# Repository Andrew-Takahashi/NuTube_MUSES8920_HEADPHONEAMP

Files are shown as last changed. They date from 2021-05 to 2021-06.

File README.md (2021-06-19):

# NuTube_MUSES8920_HEADPHONEAMP

## Version 2 updated

Version 1の配線ミスを修正し，オペアンプを両電源化．

ついでにアノード負荷を変更して2.5+-1Vで使えるように調整．

これによりNuTube単体での増幅率は約3.38倍(10.59 dB)に．

さらにオペアンプのバイアス電流をキャンセルするための抵抗用パッドを追加(R7,R11)．

電源回りのEMIフィルタをコモンモードチョークコイル + 貫通コンデンサで強化．

頑張って小型化して100 * 100 mmにした．

まだ動作確認してないので自己責任でどうぞ．

## Version 1

名前の通りNuTubeとMUSES8920を使ったヘッドホンアンプ．
現状ではNuTubeの配線を間違えているので修正予定．
ついでに両電源化してオペアンプ出力カップリングコンデンサをなくす予定．

参考(前段はパクリ)
www.maroon.dti.ne.jp/jyaku9/electronic/electronic5/electronic5-2.html

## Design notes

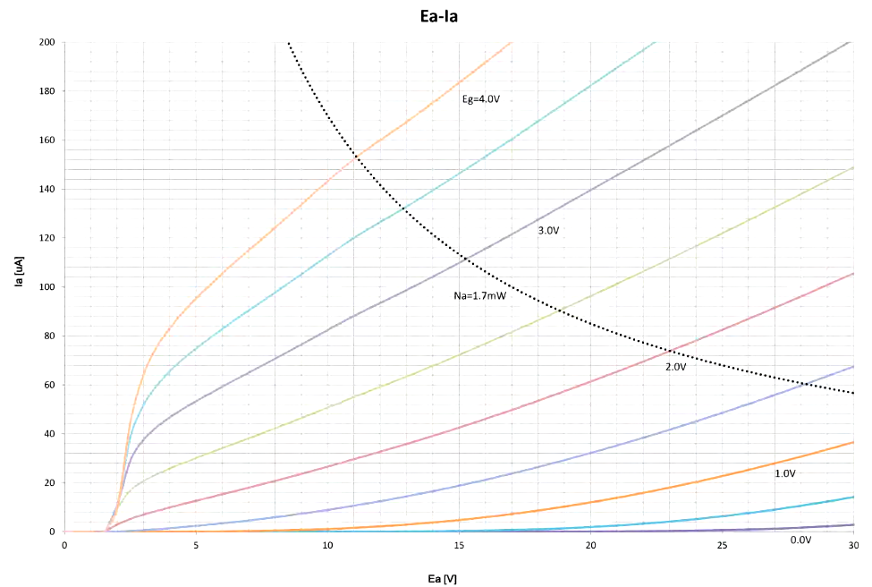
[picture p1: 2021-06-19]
Ea-Ia_.png

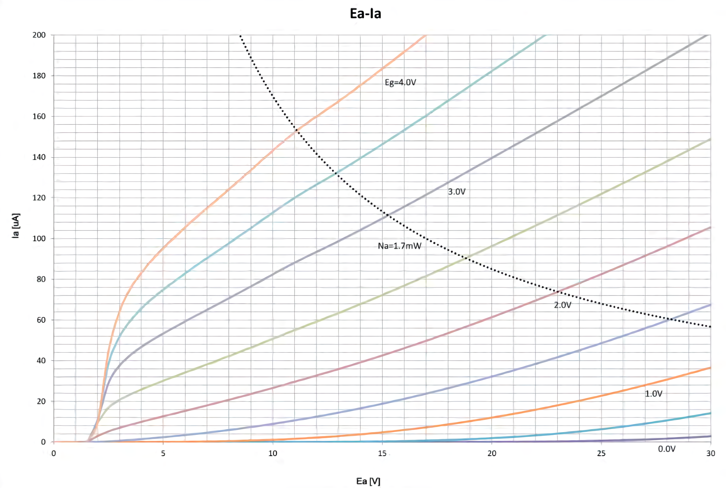
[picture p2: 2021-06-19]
Ea-Ia__.png

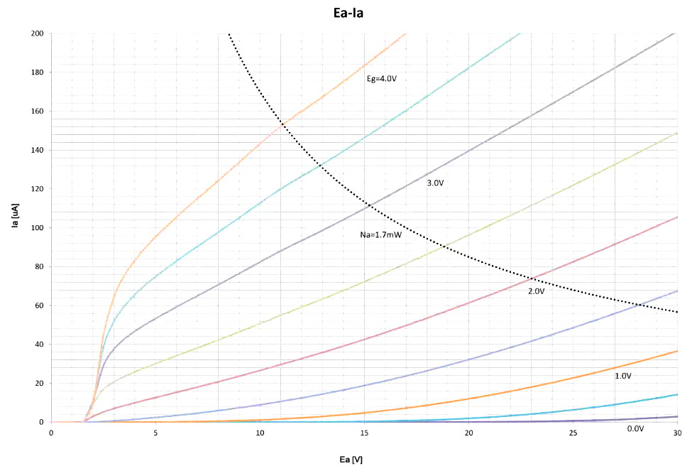
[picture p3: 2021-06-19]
Ea-Ia_.jpg

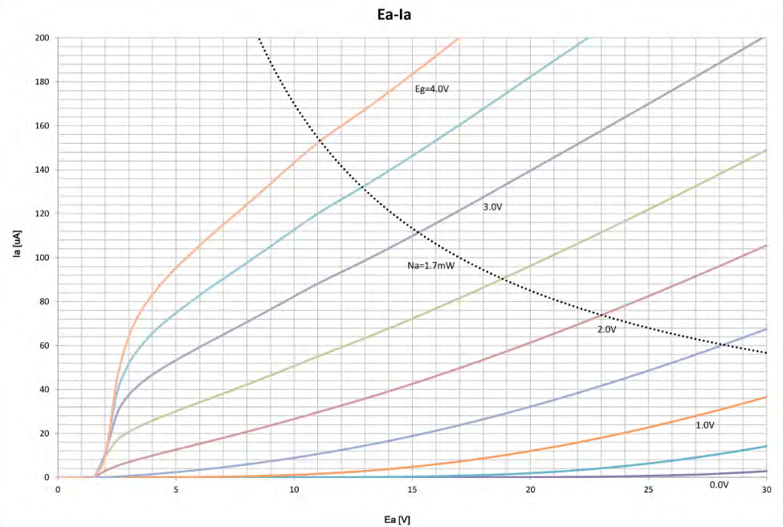
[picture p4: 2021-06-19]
Ea-Ia.bmp

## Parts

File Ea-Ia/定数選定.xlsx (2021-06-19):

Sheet: Anode Load
Load line
Ra | Intercept | Slope
100 | 150 | -10
110 | 136.3636364 | -9.090909091
120 | 125 | -8.333333333
130 | 115.3846154 | -7.692307692
150 | 100 | -6.666666667
160 | 93.75 | -6.25
180 | 83.33333333 | -5.555555556
200 | 75 | -5
220 | 68.18181818 | -4.545454545
240 | 62.5 | -4.166666667
270 | 55.55555556 | -3.703703704
300 | 50 | -3.333333333
330 | 45.45454545 | -3.03030303
Eg-Ea
 | 100k |  | 120k |  | 150k
Eg | Ea | Ia | Ea | Ia | Ea | Ia
4 | 5.28 | 98.11 | 4.39 | 88.3 | 3.55 | 76.55
3.5 | 6.35 | 85.68 | 5.43 | 78.31 | 4.49 | 70.24
3 | 8.03 | 70.81 | 7.29 | 66.69 | 6.01 | 59.39
2.5 | 9.9 | 50.22 | 9.34 | 47.81 | 8.41 | 43.85
2 | 11.88 | 32.21 | 11.32 | 30.48 | 10.75 | 28.81 |  | 14.63 | 42.66
1.5 | 13.49 | 15.41 | 13.3 | 14.98 | 12.94 | 14.2 |  | 14.443 | 40.905
1 | 14.63 | 42.66 | 14.54 | 41.78 | 14.443 | 40.905
Gain | -3.116666667 |  | -3.383333333 |  | -3.631 |  |  | 14.5365 | 41.7825
 | 9.873807123 |  | 10.58689575 |  | 11.20052498
 | slope | intercept | slope | intercept | slope | intercept
 | -3.85 | 19.56166667 | -4.03 | 19.39166667 | -4.74 | 20.24
Eg | Ea | RMS | Ea | RMS | Ea | RMS
4 | 4.161666667 | 1.250669444 | 3.271666667 | 1.250669444 | 1.28 | 5.1529
3.5 | 6.086666667 | 0.06934444444 | 5.286666667 | 0.02054444444 | 3.65 | 0.7056
3 | 8.011666667 | 0.0003361111111 | 7.301666667 | 0.0001361111111 | 6.02 | 0.0001
2.5 | 9.936666667 | 0.001344444444 | 9.316666667 | 0.0005444444444 | 8.39 | 0.0004
2 | 11.86166667 | 0.0003361111111 | 11.33166667 | 0.0001361111111 | 10.76 | 0.0001
1.5 | 13.78666667 | 0.08801111111 | 13.34666667 | 0.002177777778 | 13.13 | 0.0361
1 | 15.71166667 | 1.170002778 | 15.36166667 | 0.6751361111 | 15.5 | 1.117249
linearity error(2.5+-1V) |  | 0.03187444444 |  | 0.004707777778 |  | 0.14846
 |  | Dumping
 | Impedance | 16 | 18 | 20 | 22 | 24 | 27 | 30 | 33 | 36 | 39 | 43 | 47 | 51 | 56 | 62 | 68 | 75
MPH-2 | 32 | -0.3333333333 | -0.28 | -0.2307692308 | -0.1851851852 | -0.1428571429 | -0.08474576271 | -0.03225806452 | 0.01538461538 | 0.05882352941 | 0.0985915493 | 0.1466666667 | 0.1898734177 | 0.2289156627 | 0.2727272727 | 0.3191489362 | 0.36 | 0.4018691589
SE-CH9T | 26 | -0.2380952381 | -0.1818181818 | -0.1304347826 | -0.08333333333 | -0.04 | 0.01886792453 | 0.07142857143 | 0.1186440678 | 0.1612903226 | 0.2 | 0.2463768116 | 0.2876712329 | 0.3246753247 | 0.3658536585 | 0.4090909091 | 0.4468085106 | 0.4851485149
E500 | 16 | 0 | 0.05882352941 | 0.1111111111 | 0.1578947368 | 0.2 | 0.2558139535 | 0.3043478261 | 0.3469387755 | 0.3846153846 | 0.4181818182 | 0.4576271186 | 0.4920634921 | 0.5223880597 | 0.5555555556 | 0.5897435897 | 0.619047619 | 0.6483516484
 |  | 0.02947845805 | 0.03039158111 | 0.03088226474 | 0.03104476908 | 0.03095510204 | 0.03047668952 | 0.02971763721 | 0.0287848582 | 0.02775230999 | 0.02667081994 | 0.02521086799 | 0.02377657488 | 0.02239771438 | 0.02077519517 | 0.01899106934 | 0.01738461615 | 0.01572072192

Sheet: Parts List
 |  |  |  | D | P | L
C1 | EMIフィルタ |  |  |  |  |  | https://akizukidenshi.com/catalog/g/gP-05494/ | 200
C2 | EMIフィルタ |  |  |  |  |  | https://akizukidenshi.com/catalog/g/gP-05494/
C3 | 3.3V IGO IN | 0.1 | ECHU | 3225 |  |  | https://akizukidenshi.com/catalog/g/gP-14342/ | 40
C4 | 3.3V IGO IN | 0.1 | ECHU | 3225 |  |  | https://akizukidenshi.com/catalog/g/gP-14342/ | 40
C5 | 3.3V IGO OUT | 100 | OS | 6.3 | 2.5 | 6 | https://akizukidenshi.com/catalog/g/gP-08290/ | 40
C6 | 3.3V IGO OUT | 100 | OS | 6.3 | 2.5 | 6 | https://akizukidenshi.com/catalog/g/gP-08290/ | 40
C7 | COUPLE IN | 100 | KZ | 10 | 5 | 16 | https://akizukidenshi.com/catalog/g/gP-04608/ | 30
C8 | BIAS | 22 | ES | 6.3 | 2.5 | 11 | https://akizukidenshi.com/catalog/g/gP-04625/ | 20
C9 | COUPLE IN | 100 | KZ | 10 | 5 | 16 | https://akizukidenshi.com/catalog/g/gP-04608/ | 30
C10 | BIAS | 22 | ES | 6.3 | 2.5 | 11 | https://akizukidenshi.com/catalog/g/gP-04625/ | 20
C11 | Anode CP | 100 | OS | 6.3 | 2.5 | 6 | https://akizukidenshi.com/catalog/g/gP-08290/ | 40
C12 | Anode C | 0.1 | ECHU | 3225 |  |  | https://akizukidenshi.com/catalog/g/gP-14342/ | 40
C13 | Filament CP | 22 | ES | 6.3 | 2.5 | 11 | https://akizukidenshi.com/catalog/g/gP-04625/ | 20
C14 | Filament CP | 22 | ES | 6.3 | 2.5 | 11 | https://akizukidenshi.com/catalog/g/gP-04625/ | 20
C15 | Anode C | 0.1 | ECHU | 3225 |  |  | https://akizukidenshi.com/catalog/g/gP-14342/ | 40
C16 | Anode CP | 100 | OS | 6.3 | 2.5 | 6 | https://akizukidenshi.com/catalog/g/gP-08290/ | 40
C17 | COUPLE AMP | 100 | KZ | 10 | 5 | 16 | https://akizukidenshi.com/catalog/g/gP-04608/ | 30
C18 | COUPLE AMP | 100 | KZ | 10 | 5 | 16 | https://akizukidenshi.com/catalog/g/gP-04608/ | 30
C19 | DCPL AMP | 100 | OS | 6.3 | 2.5 | 6 | https://akizukidenshi.com/catalog/g/gP-08290/ | 40
C20 | DCPL AMP | 100 | OS | 6.3 | 2.5 | 6 | https://akizukidenshi.com/catalog/g/gP-08290/ | 40
C21 | DCPL AMP | 0.1 | ECHU | 3225 |  |  | https://akizukidenshi.com/catalog/g/gP-14342/ | 40
C22 | DCPL AMP | 0.1 | ECHU | 3225 |  |  | https://akizukidenshi.com/catalog/g/gP-14342/ | 40
R1 | 33k
R2 | 150
R3 | 33k
R4 | 150
R5 | 120k
R6 | 120k
R7 | 1M
R8 | 1k
R9 | 1k
R10 | 75
R11 | 1M
R12 | 1k
R13 | 1k
R14 | 75

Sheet: Buy List
 |  | 単価 | 個数 | 小計
ＥＭＩフィルタ（ムラタエミフィル・フィールドスルーコンデンサー） １μＦ（１０個入） | https://akizukidenshi.com/catalog/g/gP-05494/ | 200 | 1 | 200
メタライズド積層フィルムコンデンサー ０．１μＦ１６Ｖ パナソニックＥＣＨＵ | https://akizukidenshi.com/catalog/g/gP-14342/ | 40 | 20 | 800
導電性高分子アルミ固体電解コンデンサー ＯＳ－ＣＯＮ １００μＦ１６Ｖ１０５℃ | https://akizukidenshi.com/catalog/g/gP-08290/ | 40 | 20 | 800
オーディオ用電解コンデンサー１００μＦ２５Ｖ８５℃ ニチコンＭＵＳＥ・ＫＺ | https://akizukidenshi.com/catalog/g/gP-04608/ | 30 | 10 | 300
オーディオ用無極性電解コンデンサー２２μＦ２５Ｖ８５℃ ニチコンＭＵＳＥ・ＥＳ | https://akizukidenshi.com/catalog/g/gP-04625/ | 20 | 10 | 200
マイクロＵＳＢコネクタ 電源供給用 | https://akizukidenshi.com/catalog/g/gC-10398/ | 30 | 10 | 300
３．５ｍｍ４極ミニジャック 基板取付用 ＭＪ－４ＰＰ－９ | https://akizukidenshi.com/catalog/g/gC-06070/ | 50 | 4 | 200
多回転半固定ボリューム たて型 ３２９６Ｗ １０ｋΩ ［１０３］ | https://akizukidenshi.com/catalog/g/gP-00975/ | 120 | 8 | 960
コモンモードチョーク（ノイズフィルタ） ＤＬＷ５ＢＴＭ１４２ＴＱ２ | https://akizukidenshi.com/catalog/g/gP-15303/ | 100 | 10 | 1000
1608(0603) チップ抵抗 75Ω | https://www.marutsu.co.jp/pc/i/856891/ | 5 | 10 | 50
1608(0603) チップ抵抗 150Ω | https://www.marutsu.co.jp/pc/i/856769/ | 5 | 10 | 50
1608(0603) チップ抵抗 1kΩ | https://www.marutsu.co.jp/pc/i/856745/ | 5 | 20 | 100
1608(0603) チップ抵抗 33kΩ | https://www.marutsu.co.jp/pc/i/856829/ | 5 | 10 | 50
1608(0603) チップ抵抗 120kΩ | https://www.marutsu.co.jp/pc/i/856760/ | 5 | 10 | 50
1608(0603) チップ抵抗 470kΩ | https://www.marutsu.co.jp/pc/i/856859/ | 5 | 20 | 100
1608(0603) チップ抵抗 1MΩ | https://www.marutsu.co.jp/pc/i/856748/ | 5 | 20 | 100

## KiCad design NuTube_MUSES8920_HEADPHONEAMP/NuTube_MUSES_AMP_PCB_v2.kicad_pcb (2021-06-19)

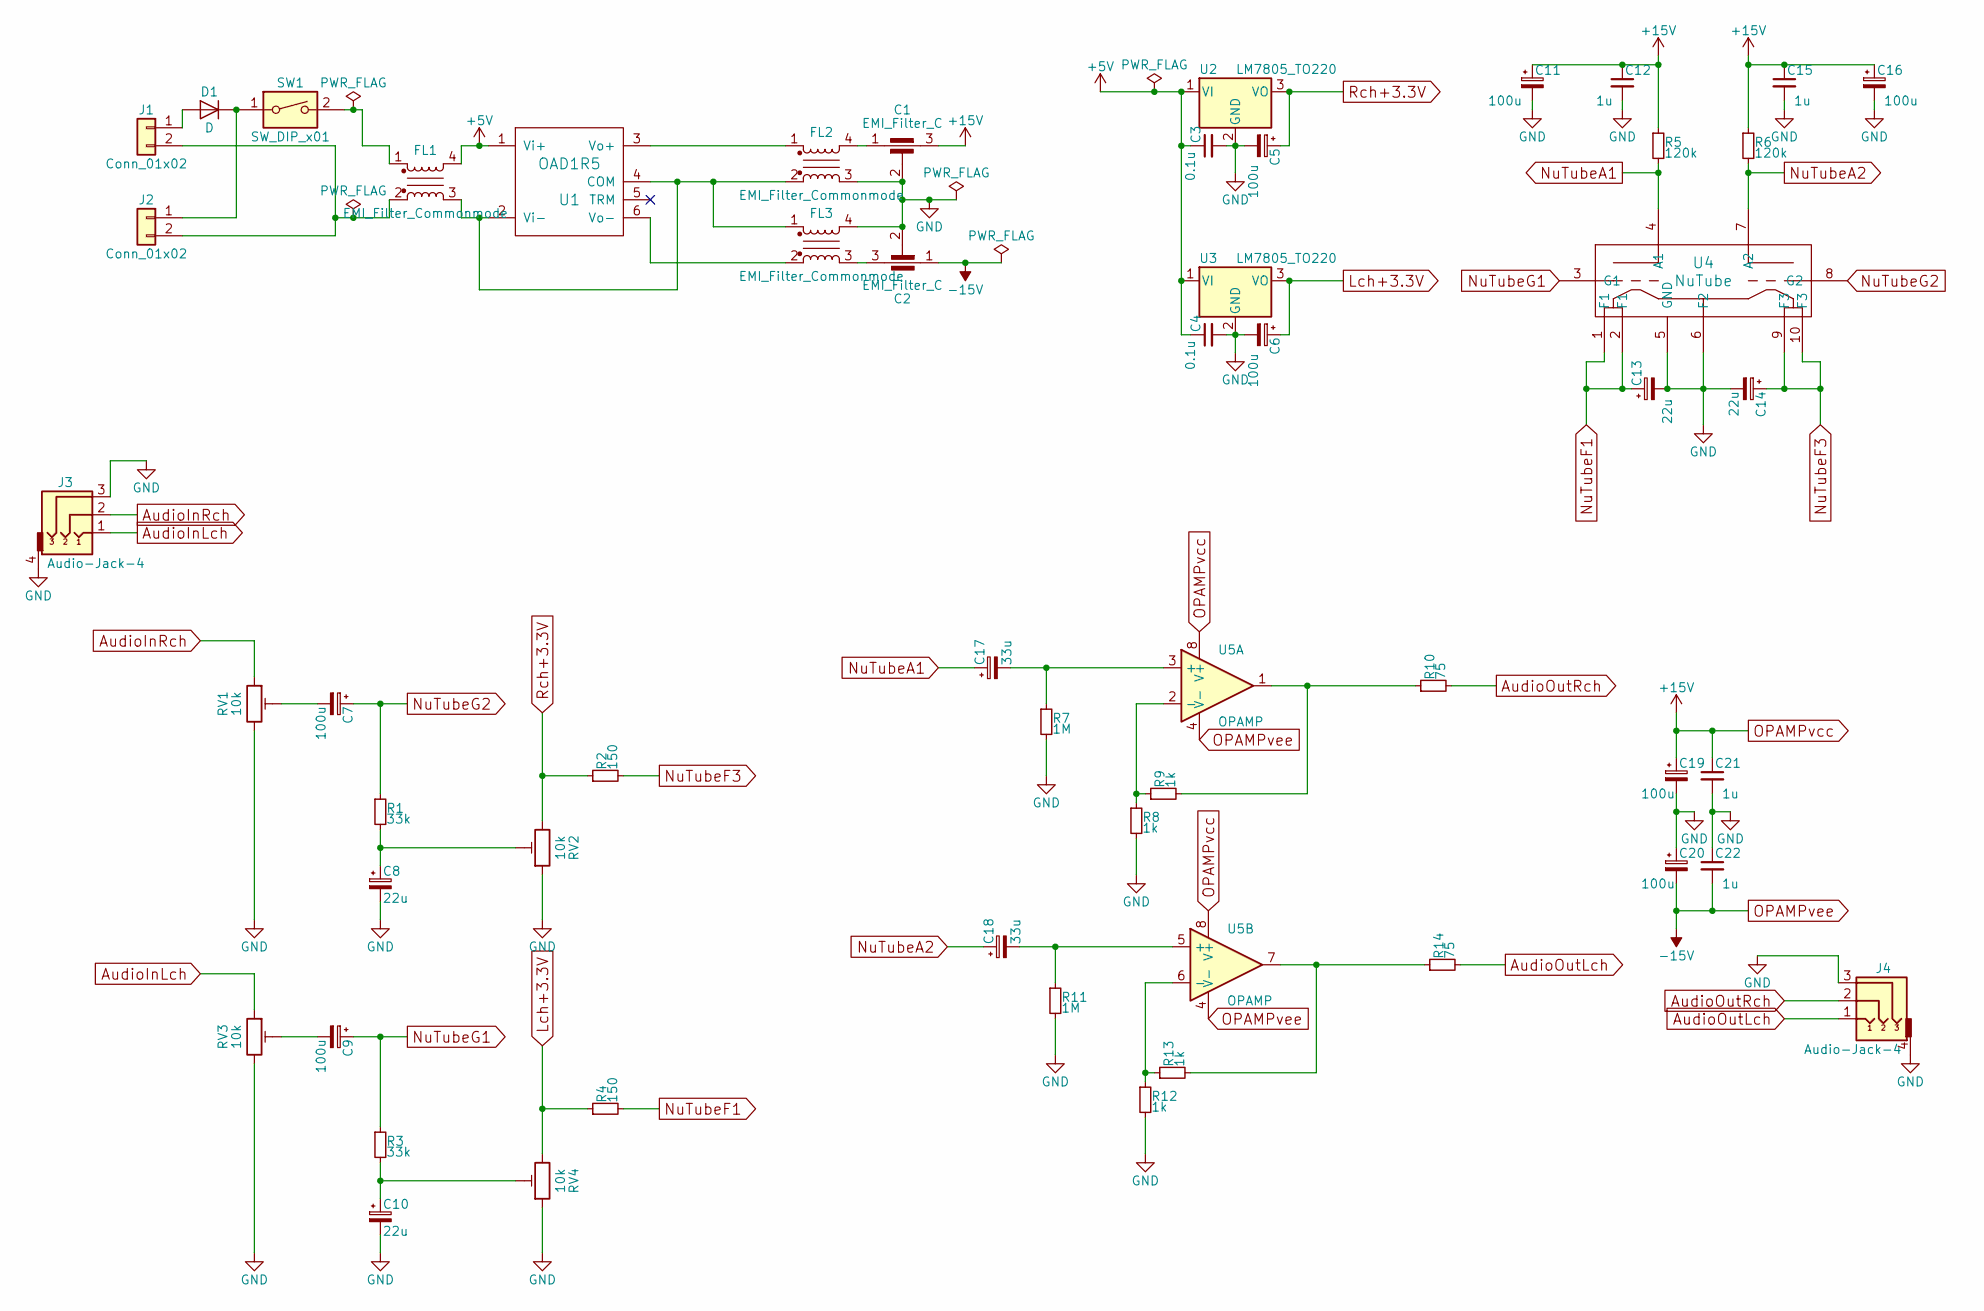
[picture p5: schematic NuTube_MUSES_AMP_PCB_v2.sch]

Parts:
C1, C2: EMI_Filter_C; NFM21PC
C3, C4: 0.1u; C_0603_HandSoldering
C5, C6, C11, C16, C19, C20: 100u; CP_Radial_D6.3mm_P2.50mm
C7, C9: 100u; CP_Radial_D10.0mm_P5.00mm
C8, C10, C13, C14: 22u; CP_Radial_D6.3mm_P2.50mm
C12, C15, C21, C22: 1u; ECHU(X)G3
C17, C18: 33u; CP_Radial_D10.0mm_P5.00mm
D1: D; D_DO-41_SOD81_P7.62mm_Horizontal
FL1: EMI_Filter_Commonmode; DLW5BTM
FL2, FL3: EMI_Filter_Commonmode; ACM2520-2P
J1: Conn_01x02; 006P_Holder
J2: Conn_01x02; microUSB(SupplyOnly)
J3, J4: Audio-Jack-4; MJ-4PP-9
R1, R3: 33k; R_0603_HandSoldering
R2, R4: 150; R_0603_HandSoldering
R5, R6: 120k; R_0603_HandSoldering
R7, R11: 1M; R_0603_HandSoldering
R8, R9, R12, R13: 1k; R_0603_HandSoldering
R10, R14: 75; R_0603_HandSoldering
RV1, RV2, RV3, RV4: 10k; LTP3296
SW1: SW_DIP_x01; 2MS6-T1-B3-M1-QE
U1: OAD1R5; OAD1R5-IIOO
U2, U3: LM7805_TO220; SOT-89-3_Handsoldering
U4: NuTube; NuTube_Conversion_Board
U5: OPAMP; DIP-8_W7.62mm_Socket_LongPads

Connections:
+5V: C3.1, C4.1, FL1.4, U1.1 (Vi+), U2.1 (VI), U3.1 (VI)
AudioInLch: J3.1, RV3.1
AudioInRch: J3.2, RV1.1
AudioOutLch: J4.1, R14.2
AudioOutRch: J4.2, R10.2
GND: C1.2, C2.2, C3.2, C4.2, C5.2, C6.2, C8.2, C10.2, C11.2, C12.2, C13.2, C14.2, C15.2, C16.2, C19.2, C20.1, C21.2, C22.1, FL2.3, FL3.4, J3.3, J3.4, J4.3, J4.4, R7.2, R8.2, R11.2, R12.2, RV1.3, RV2.1, RV3.3, RV4.1, U2.2 (GND), U3.2 (GND), U4.5 (GND), U4.6 (F2)
Lch+3.3V: C6.1, R4.1, RV4.3, U3.3 (VO)
unnamed: C1.1, FL2.4
unnamed: C2.3, FL3.3
unnamed: C7.2, RV1.2
unnamed: C8.1, R1.2, RV2.2
unnamed: C9.2, RV3.2
unnamed: C10.1, R3.2, RV4.2
unnamed: C17.2, R7.1, U5.3 (+)
unnamed: C18.2, R11.1, U5.5 (+)
unnamed: D1.1 (K), J2.1, SW1.1
unnamed: D1.2 (A), J1.1
unnamed: FL1.1, SW1.2
unnamed: FL1.2, J1.2, J2.2
unnamed: FL1.3, FL2.2, FL3.1, U1.2 (Vi-), U1.4 (COM)
unnamed: FL2.1, U1.3 (Vo+)
unnamed: FL3.2, U1.6 (Vo-)
unnamed: R8.1, R9.1, U5.2 (-)
unnamed: R9.2, R10.1, U5.1
unnamed: R12.1, R13.1, U5.6 (-)
unnamed: R13.2, R14.1, U5.7
NuTubeA1: C17.1, R5.2, U4.4 (A1)
NuTubeA2: C18.1, R6.2, U4.7 (A2)
NuTubeF1: C13.1, R4.2, U4.1 (F1), U4.2 (F1)
NuTubeF3: C14.1, R2.2, U4.9 (F3), U4.10 (F3)
NuTubeG1: C9.1, R3.1, U4.3 (G1)
NuTubeG2: C7.1, R1.1, U4.8 (G2)
OPAMPvcc: C1.3, C11.1, C12.1, C15.1, C16.1, C19.1, C21.1, R5.1, R6.1, U5.8 (V+)
OPAMPvee: C2.1, C20.2, C22.2, U5.4 (V-)
Rch+3.3V: C5.1, R2.1, RV2.3, U2.3 (VO)

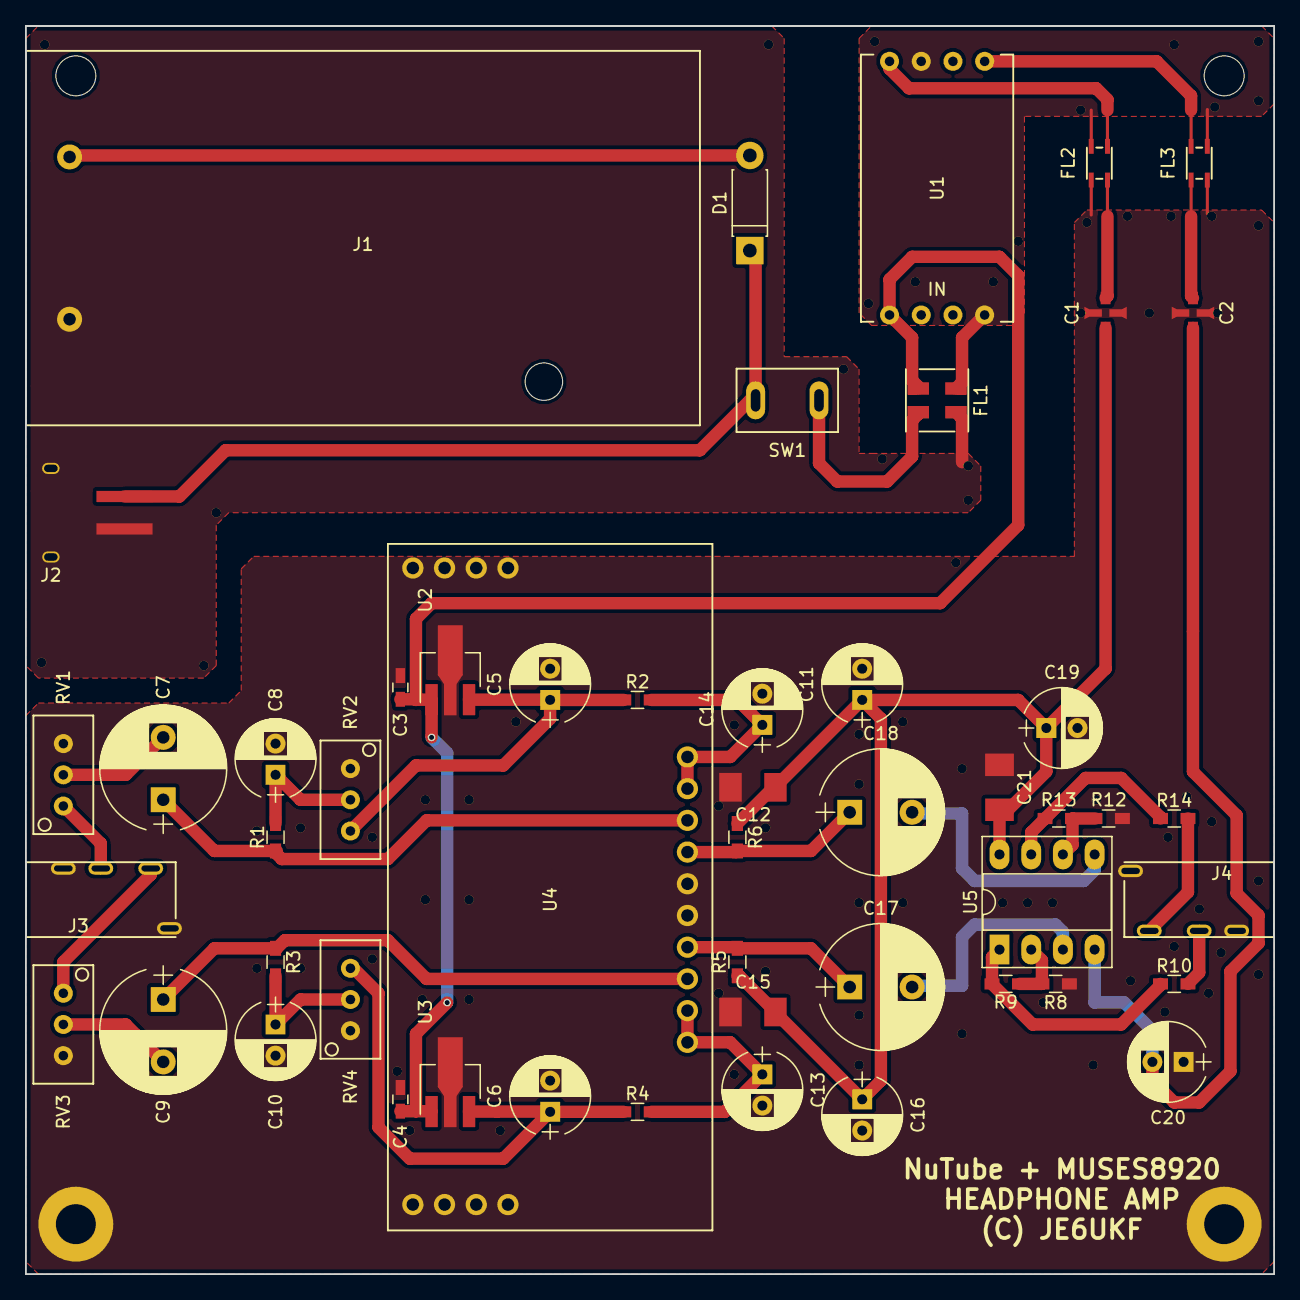
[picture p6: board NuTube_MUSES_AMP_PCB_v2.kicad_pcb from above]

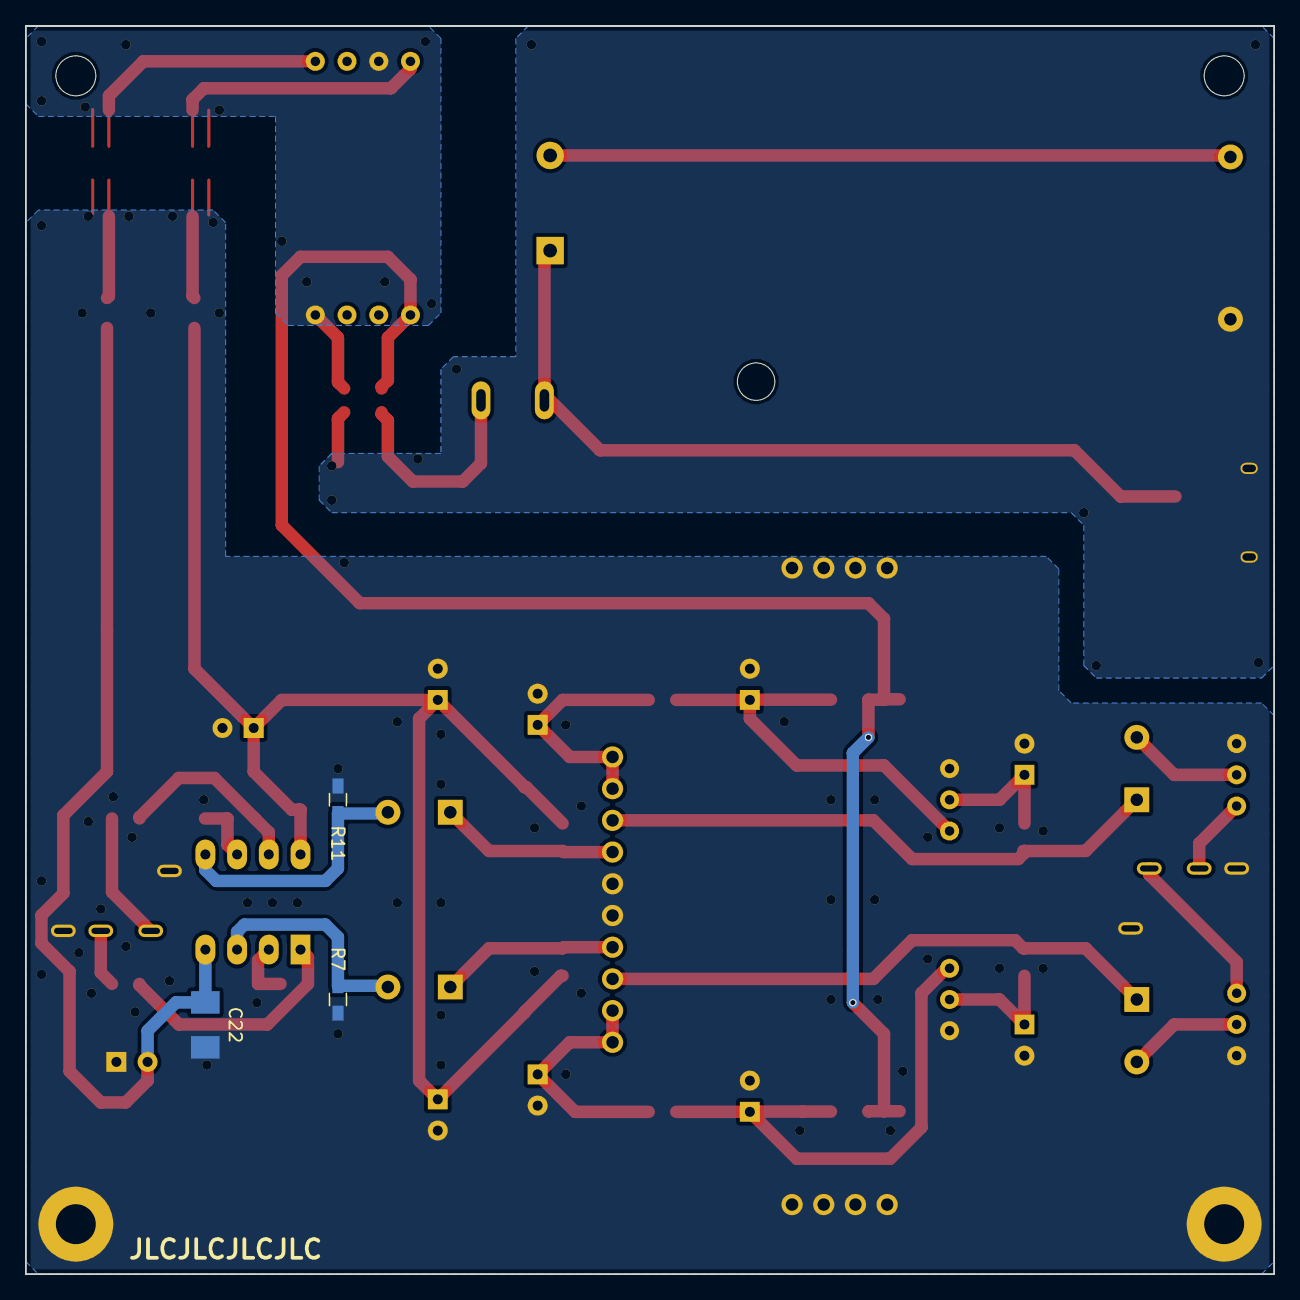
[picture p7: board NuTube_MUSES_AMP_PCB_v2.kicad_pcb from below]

Board: 2 copper layers, 100.0 x 100.0 mm, 54 parts (3 on the bottom side), 35 nets.

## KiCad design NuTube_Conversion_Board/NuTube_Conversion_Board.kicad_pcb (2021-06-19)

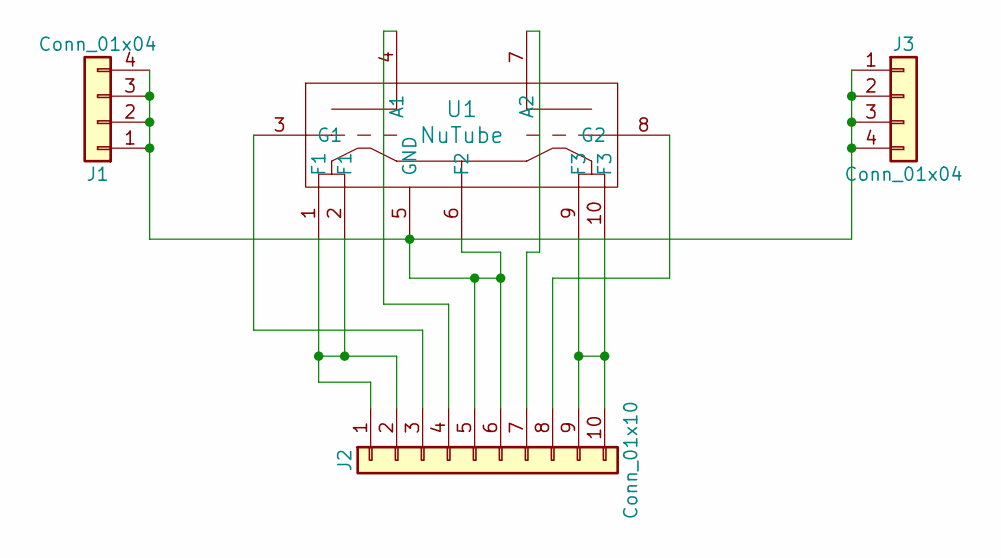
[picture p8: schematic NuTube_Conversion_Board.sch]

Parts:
J1, J3: Conn_01x04; Pin_Header_Straight_1x04_Pitch2.54mm
J2: Conn_01x10; Pin_Header_Straight_1x10_Pitch2.54mm
U1: NuTube

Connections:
unnamed: J1.1, J1.2, J1.3, J1.4, J2.5, J2.6, J3.1, J3.2, J3.3, J3.4, U1.5 (GND), U1.6 (F2)
unnamed: J2.1, J2.2, U1.1 (F1), U1.2 (F1)
unnamed: J2.3, U1.3 (G1)
unnamed: J2.4, U1.4 (A1)
unnamed: J2.7, U1.7 (A2)
unnamed: J2.8, U1.8 (G2)
unnamed: J2.9, J2.10, U1.9 (F3), U1.10 (F3)

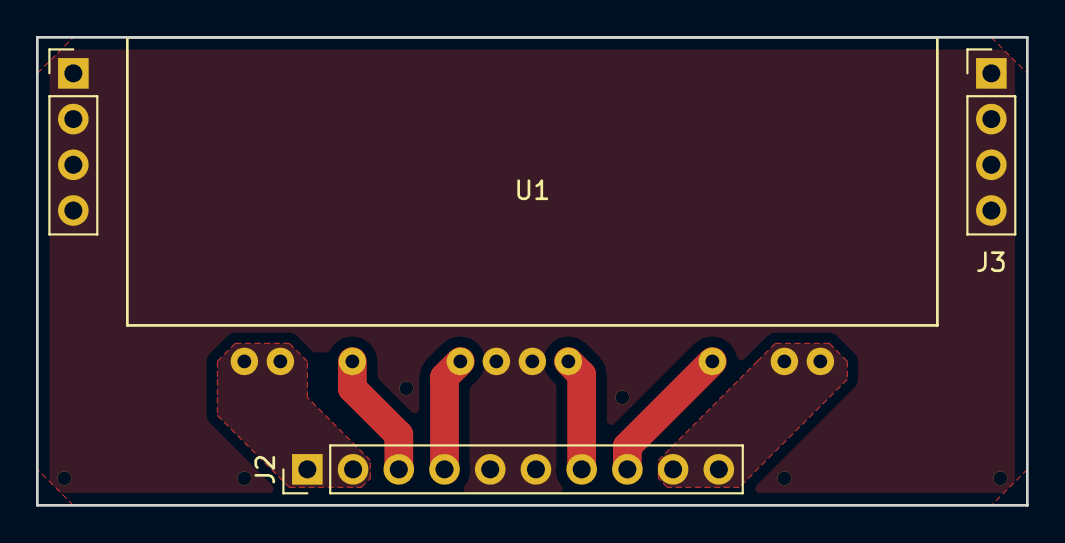
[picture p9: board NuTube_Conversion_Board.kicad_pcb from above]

Board: 2 copper layers, 55.0 x 26.0 mm, 4 parts (0 on the bottom side), 7 nets.

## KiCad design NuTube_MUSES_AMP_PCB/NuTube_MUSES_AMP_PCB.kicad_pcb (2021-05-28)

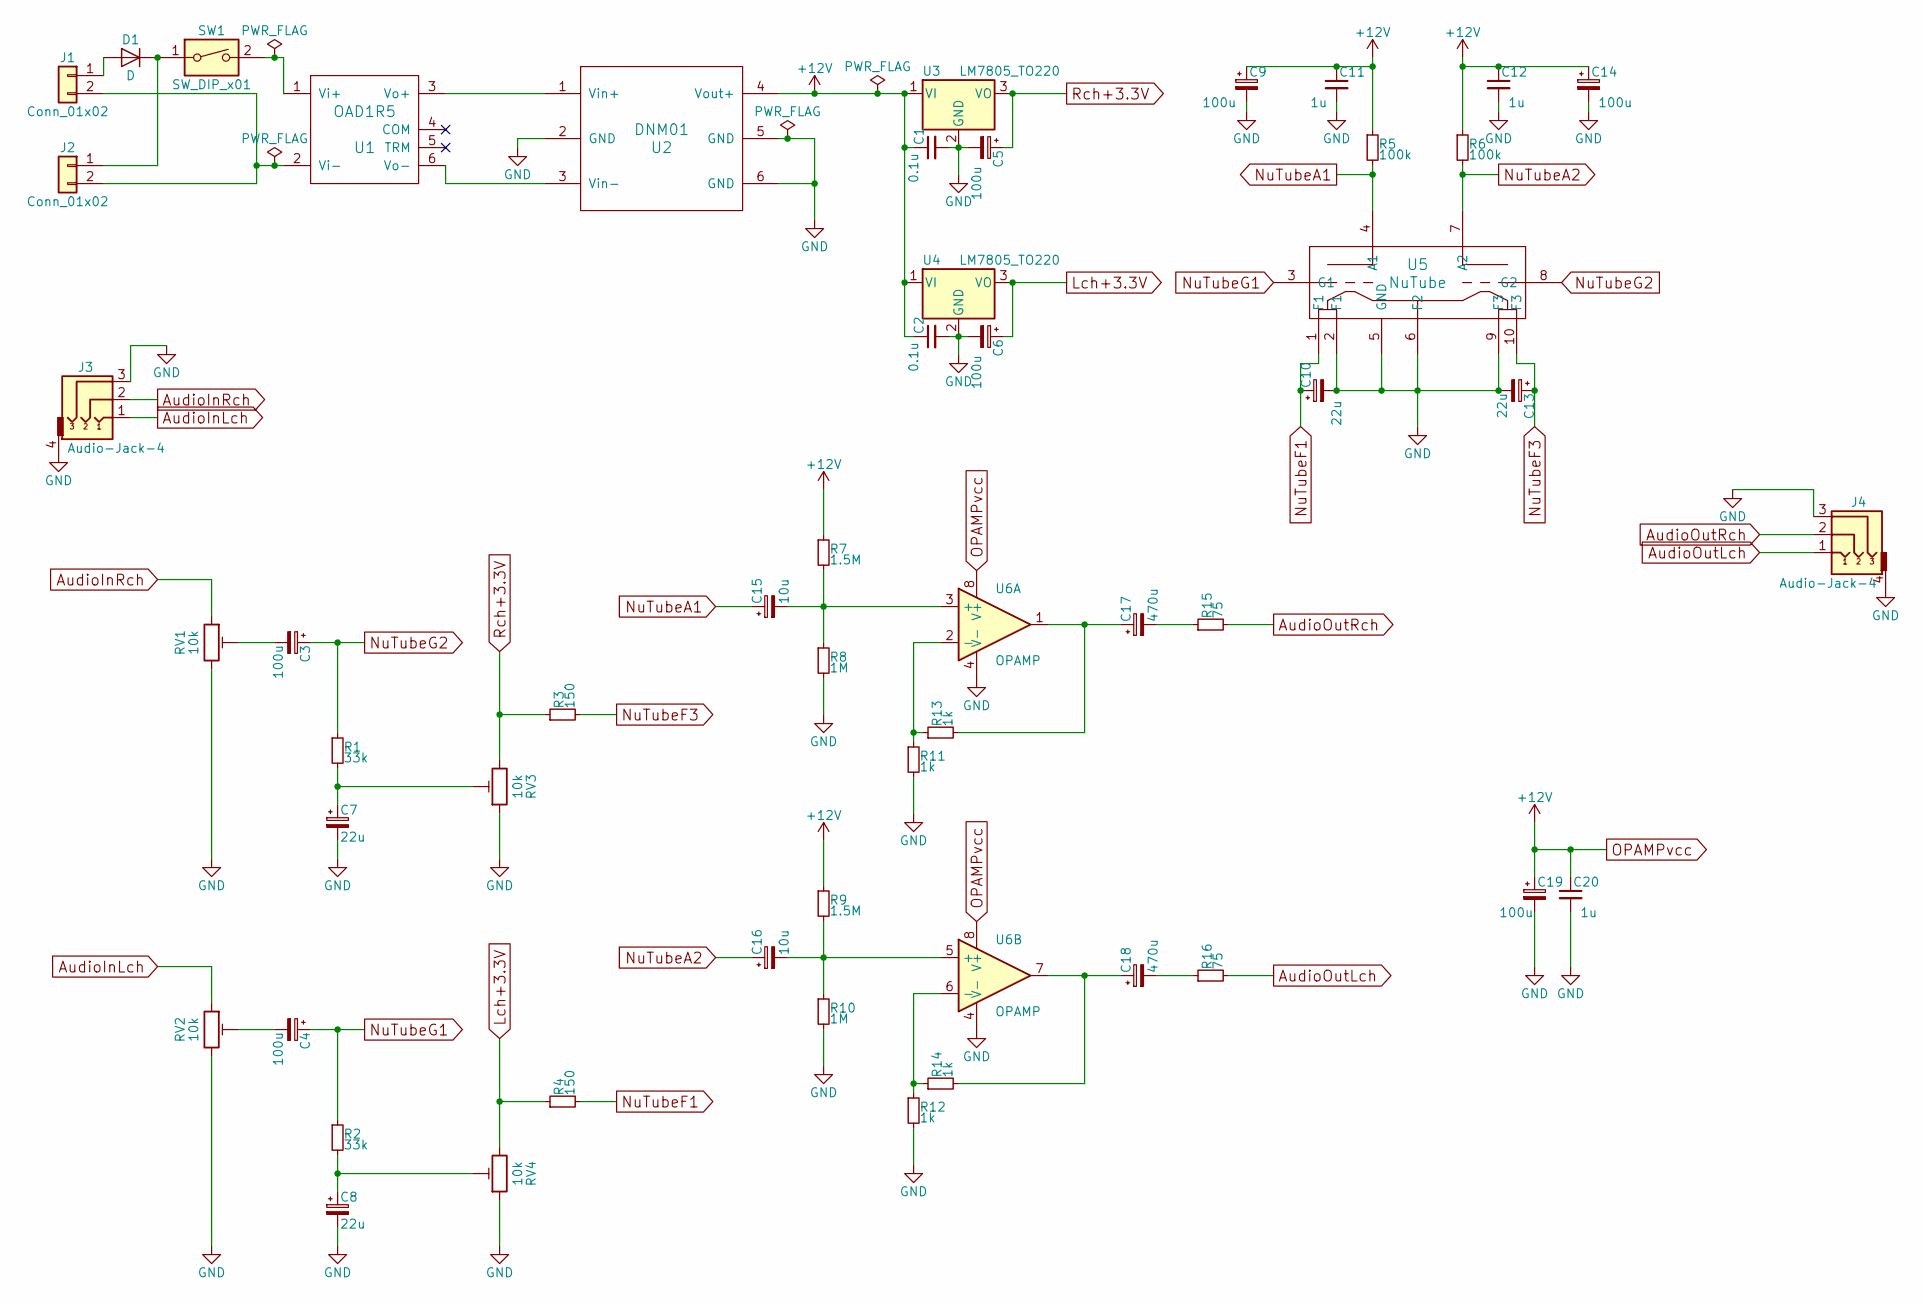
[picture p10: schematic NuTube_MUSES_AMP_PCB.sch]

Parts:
C1, C2: 0.1u; C_0603_HandSoldering
C3, C4, C5, C6, C9, C14, C19: 100u; CP_Radial_D6.3mm_P2.50mm
C7, C8, C10, C13: 22u; CP_Radial_D6.3mm_P2.50mm
C11, C12, C20: 1u; C_0603_HandSoldering
C15, C16: 10u; CP_Radial_D5.0mm_P2.50mm
C17, C18: 470u; CP_Radial_D16.0mm_P7.50mm
D1: D; D_DO-41_SOD81_P7.62mm_Horizontal
J1: Conn_01x02; 006P_Holder
J2: Conn_01x02; microUSB(SupplyOnly)
J3, J4: Audio-Jack-4; MJ-4PP-9
R1, R2: 33k; R_Axial_DIN0207_L6.3mm_D2.5mm_P7.62mm_Horizontal
R3, R4: 150; R_Axial_DIN0207_L6.3mm_D2.5mm_P7.62mm_Horizontal
R5, R6: 100k; R_Axial_DIN0207_L6.3mm_D2.5mm_P7.62mm_Horizontal
R7, R9: 1.5M; R_Axial_DIN0207_L6.3mm_D2.5mm_P7.62mm_Horizontal
R8, R10: 1M; R_Axial_DIN0207_L6.3mm_D2.5mm_P7.62mm_Horizontal
R11, R12, R13, R14: 1k; R_Axial_DIN0207_L6.3mm_D2.5mm_P7.62mm_Horizontal
R15, R16: 75; R_Axial_DIN0207_L6.3mm_D2.5mm_P7.62mm_Horizontal
RV1, RV2, RV3, RV4: 10k; LTP3296
SW1: SW_DIP_x01; 2MS6-T1-B3-M1-QE
U1: OAD1R5
U2: DNM01
U3, U4: LM7805_TO220; SOT-223-3_TabPin2
U5: NuTube
U6: OPAMP; DIP-8_W7.62mm_Socket_LongPads

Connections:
AudioInLch: J3.1, RV2.1
AudioInRch: J3.2, RV1.1
AudioOutLch: J4.1, R16.2
AudioOutRch: J4.2, R15.2
GND: C1.2, C2.2, C5.2, C6.2, C7.2, C8.2, C9.2, C10.2, C11.2, C12.2, C13.2, C14.2, C19.2, C20.2, J3.3, J3.4, J4.3, J4.4, R8.2, R10.2, R11.2, R12.2, RV1.3, RV2.3, RV3.1, RV4.1, U2.2 (GND), U2.5 (GND), U2.6 (GND), U3.2 (GND), U4.2 (GND), U5.2 (F1), U5.5 (GND), U5.6 (F2), U5.9 (F3), U6.4 (V-)
Lch+3.3V: C6.1, R4.1, RV4.3, U4.3 (VO)
unnamed: C3.2, RV1.2
unnamed: C4.2, RV2.2
unnamed: C7.1, R1.2, RV3.2
unnamed: C8.1, R2.2, RV4.2
unnamed: C15.2, R7.2, R8.1, U6.3 (+)
unnamed: C16.2, R9.2, R10.1, U6.5 (+)
unnamed: C17.1, R13.2, U6.1
unnamed: C17.2, R15.1
unnamed: C18.1, R14.2, U6.7
unnamed: C18.2, R16.1
unnamed: D1.1 (K), J2.1, SW1.1
unnamed: D1.2 (A), J1.1
unnamed: J1.2, J2.2, U1.2 (Vi-)
unnamed: R11.1, R13.1, U6.2 (-)
unnamed: R12.1, R14.1, U6.6 (-)
unnamed: SW1.2, U1.1 (Vi+)
unnamed: U1.3 (Vo+), U2.1 (Vin+)
unnamed: U1.6 (Vo-), U2.3 (Vin-)
NuTubeA1: C15.1, R5.2, U5.4 (A1)
NuTubeA2: C16.1, R6.2, U5.7 (A2)
NuTubeF1: C10.1, R4.2, U5.1 (F1)
NuTubeF3: C13.1, R3.2, U5.10 (F3)
NuTubeG1: C4.1, R2.1, U5.3 (G1)
NuTubeG2: C3.1, R1.1, U5.8 (G2)
OPAMPvcc: C1.1, C2.1, C9.1, C11.1, C12.1, C14.1, C19.1, C20.1, R5.1, R6.1, R7.1, R9.1, U2.4 (Vout+), U3.1 (VI), U4.1 (VI), U6.8 (V+)
Rch+3.3V: C5.1, R3.1, RV3.3, U3.3 (VO)

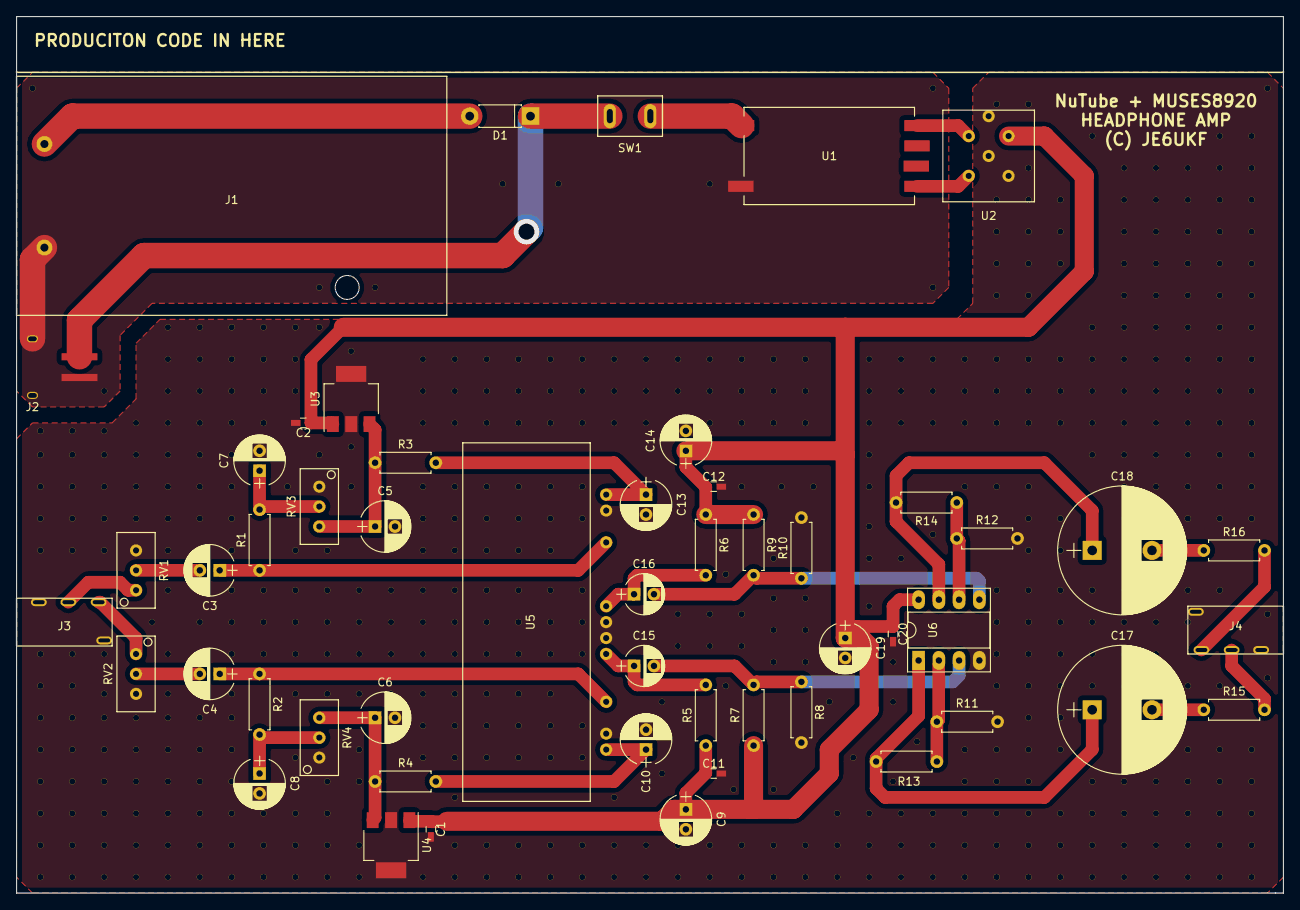
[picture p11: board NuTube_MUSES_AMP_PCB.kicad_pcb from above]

Board: 2 copper layers, 159.0 x 110.0 mm, 52 parts (0 on the bottom side), 32 nets.

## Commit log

2021-06-19 Made version 2 and Conversion board(NuTube_MUSES8920_HEADPHONEAMP and NuTube_Conversion_Board)
    [Eg=0.5V.csv, Eg=1.0V.csv, Eg=1.5V.csv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]
2021-06-19 Add document of selecting anode resistance constant.
    [Ea-Ia特性曲線.xlsx, 定数選定.xlsx]
